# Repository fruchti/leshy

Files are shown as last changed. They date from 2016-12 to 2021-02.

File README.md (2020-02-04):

# leshy

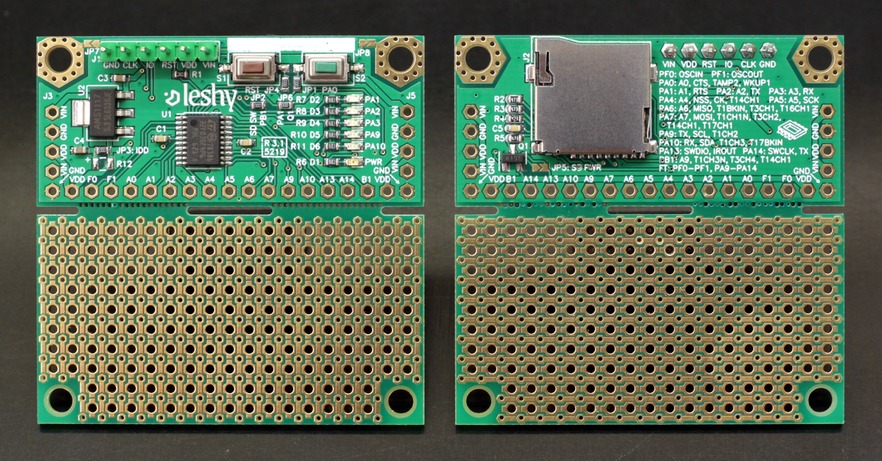
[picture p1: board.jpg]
PCB top and bottom

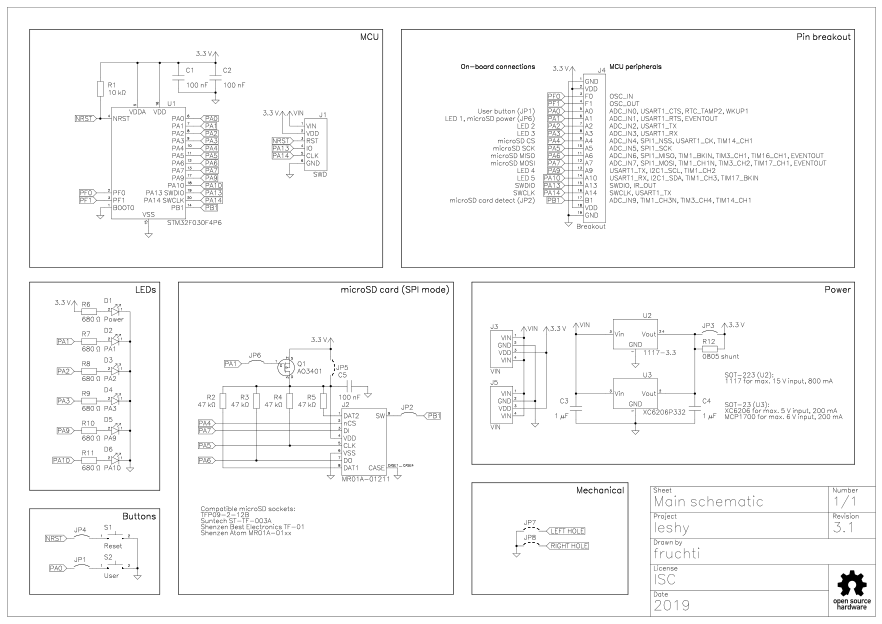
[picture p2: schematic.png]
Schematic


This is a small breakout board for the STM32F030F4P6 microcontroller,
containing:

 - An LDO, alternatively a 1117-3.3 or a MCP1700-3302 (or compatible)
 - 6 LEDs, one as a power LED, the other 5 controllable by the controller
 - Two pushbuttons, one pre-connected to reset
 - A micro-SD slot with a MOSFET for turning its power off
 - A large prototyping area designed to make both SMT and THT prototyping as
   convenient as possible

A blog post about the reasoning behind the project and about its development
process can be found [here](https://25120.org/post/leshy/).

## Demo projects

The subfolder `demo` contains some example code snippets for a quick start. Each
contains the necessary makefile for building and flashing, so no IDE has to be
installed in order to get started. However, the makefile is currently only
tested on linux.

### Flashing and debugging

The makefile currently supports two methods of flashing the controller: Either
[texane's st-link](https://github.com/texane/stlink) or OpenOCD can be used.
OpenOCD also allows debugging, so if the makefile detects a running OpenOCD
instance, it will automatically upload the firmware via OpenOCD. If there's
none running, it will fall back to `st-flash`.

Each project directory includes a OpenOCD script, so you just have to start
OpenOCD like:

```
$ openocd -f flash.cfg
```

As a matter of debugging, only text messages via semihosting are implemented so
far. These are displayed in OpenOCD. See the `debug-print` example for details.
Apart from that, of course `arm-none-eabi-gdb` or a complete IDE can be used.

## Licence

Everyting in this repository, including the demo projects is ISC licenced (see
LICENCE_ISC.md for details), with the following exceptions:

* Third-party libraries used within the demo projects and located in their
  `third_party` subfolders, contain their own licence information.
* Core and device header files, which are also located in the demo projects'
  `third_party` subfolders, are supplied by ARM Limited and STMicroelectronics,
  respecitvely. They also contain their own licence information.
* For compatibility with the Horizon default pool, this project's pool (located
  within `horizon/pool`) uses
  [the same licence as the default pool](https://github.com/horizon-eda/horizon-pool/blob/master/LICENSE.md).
* Horizon automatically copies pool items for caching to the
  `horizon/design/cache` directory. Just being copies, these files also fall
  under the terms of the
  [Horizon Pool Licence](https://github.com/horizon-eda/horizon-pool/blob/master/LICENSE.md).

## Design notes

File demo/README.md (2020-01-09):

# Demo projects

This directory contains some example code snippets for a quick start. Each
contains the necessary makefile for building and flashing, so no IDE has to be
installed in order to get started. However, the makefile is currently only
tested on Linux.

| Folder | Example description |
| --- | --- |
| `blink` | Classic minimal LED blinking example. Implemented with a timer update interrupt |
| `debug-print` | Demonstrates printing messages via semihosting while debugging |
| `FreeRTOS` | Simple FreeRTOS example with tasks blinking an LED, measuring time and transmitting via semihosting |
| `hd44780` | Basic driver for HD44780-compatible character LC displays |
| `sd` | Uses FatFs to log the internal temperature sensor's output to a CSV file on the SD card |
| `soldering_station` | Basic controller for Hakko 907 soldering irons. Includes encoder input, charlieplexed 7-segment driver, control loop, and settings storage in flash memory |
| `ws2812b-hsv` | Sets H, S, V via three potentiometers and light up a WS2812B strip uniformly |
| `ws2812b-spi` | Drives a WS2812B LED strip with the SPI peripheral and DMA |

If you want to use one of the demo projects as a starting point, here is a small
table with the MCU peripherals in use and external components the project
contains driver code for:

| Folder | Microcontroller peripherals | External components | Third-party libraries |
| --- | --- | --- | --- |
| `blink` | `TIM` | | |
| `debug-print` | | | |
| `FreeRTOS` | `SysTick` | | [FreeRTOS](https://freertos.org/) |
| `hd44780` | | HD44780-based display (4-bit mode) | |
| `sd` | `ADC` (internal temperature sensor), `SPI`, `SysTick`, `TIM` | microSD card (SPI mode) | [FatFs](http://elm-chan.org/fsw/ff/00index_e.html) |
| `soldering_station` | `ADC`, `FLASH` (non-volatile storage), `TIM` | 7-segment display (charlieplexed), rotary encoder | |
| `ws2812b-hsv` | `ADC`, `DMA`, `TIM` | WS2812B LED strip (uniform colour) | |
| `ws2812b-spi` | `DMA`, `SPI`, `TIM` | WS2812B LED strip | |

## Flashing

The makefile supports flashing the controller via
[texane's st-link](https://github.com/texane/stlink). Invoke

```
$ make program
```

to build a binary and flash it at `0x8000000`.

# Debugging

Each project directory includes a OpenOCD script, so you can start OpenOCD like:

```
$ openocd -f flash.cfg
```

As a matter of debugging, only text messages via semihosting are implemented so
far. These are displayed in OpenOCD. See the `debug-print` example for details.
Apart from that, of course `arm-none-eabi-gdb` or a complete IDE can be used.

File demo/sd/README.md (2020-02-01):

# SD card example

This example reads out the microcontroller's internal temperature sensor every
n milliseconds and saves the values to `log.csv` on the SD card. Logging is
stopped and started again by clicking the switch attached to PA0.

LED 3 (PA3) indicates ongoing initialisation, while LED 2 (PA2) is lit up as
long as logging is taking place. LED 5 (PA 10) flashes for every saved data
point. LED 1 (PA1) lights up when the SD card is turned off, since it is
connected to the same pin as the SD power MOSFET's gate.

The button should be pressed before removing the SD card, because the write
cache would not be flushed otherwise.

`plot.py` is a minimal Python script to plot a CSV file generated by the code
example.
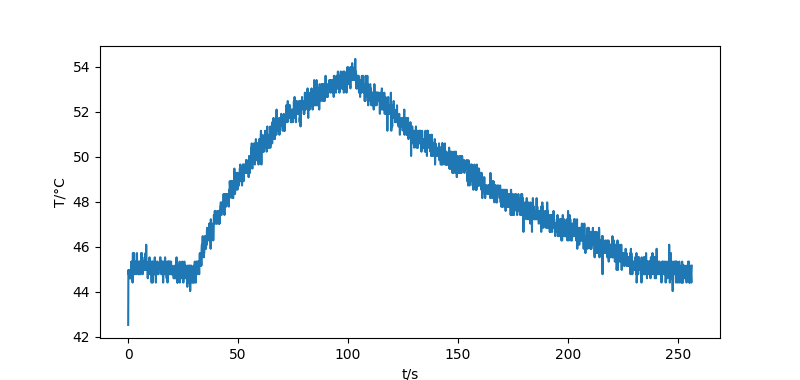
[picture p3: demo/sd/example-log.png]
Example temperature log plot


## Some notes on the code
The code just is a quick port of ELM ChaN's FatFs and could be optimised in
terms of speed and size. The former can be achieved by disabling unneeded
features in `ffconf.h` such as long file names. For the latter an
implementation using the DMA for larger blocks instead of the currently used
blocking SPI transfer.

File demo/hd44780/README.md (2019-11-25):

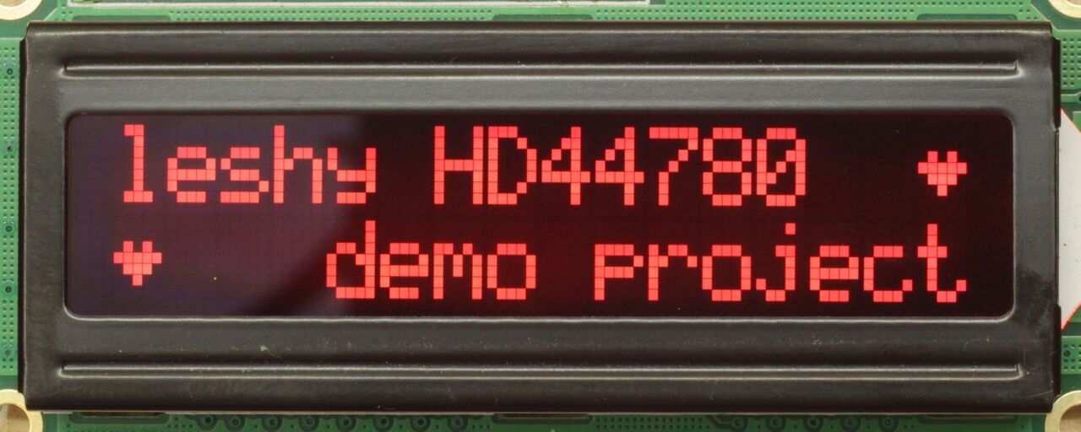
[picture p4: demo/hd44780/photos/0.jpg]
HD44780 example
# 

This is a very basic driver implementation for HD44780-compatible LC displays in
4 bit mode. Delays are blocking for simplicity. Custom characters are supported
(as shown in the photo above). The used pins can be moved around freely in
`pinning.h`, but are constrained to port A. If they have to be moved to another
port, `LCD_Init()` and `LCD_Nibble()` have to be adapted accordingly.

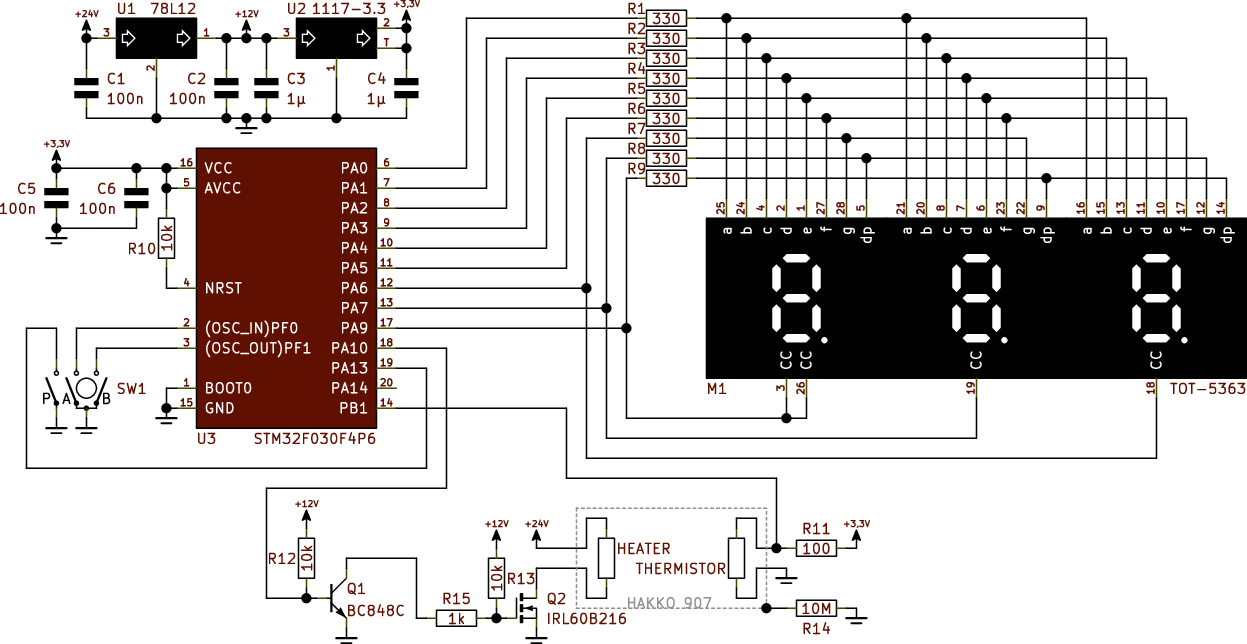
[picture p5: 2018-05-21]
demo/soldering_station/schematic/schematic.png

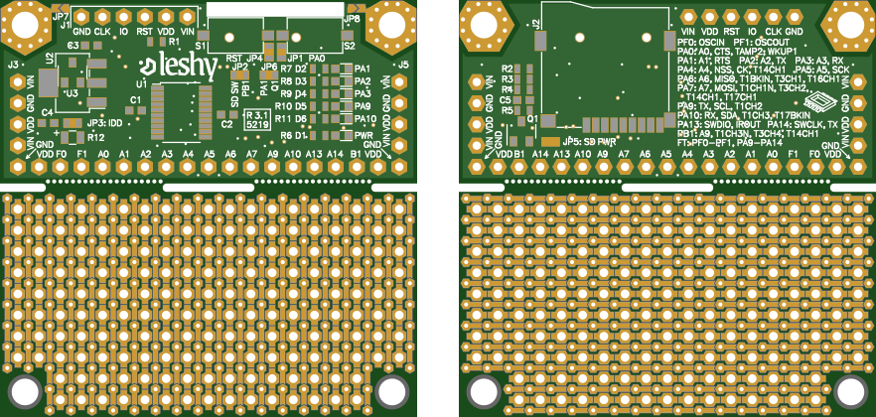
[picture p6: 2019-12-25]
layout.png

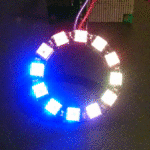
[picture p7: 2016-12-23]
demo/ws2812b-spi/demo.gif

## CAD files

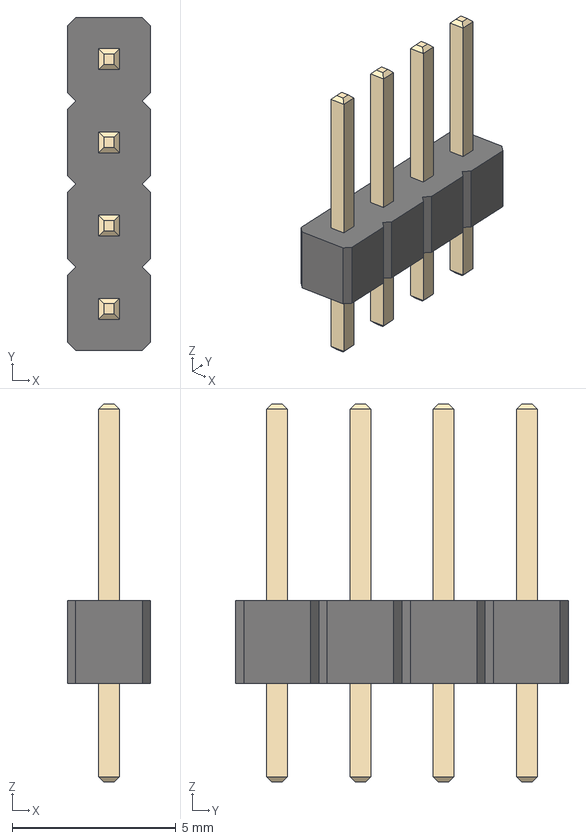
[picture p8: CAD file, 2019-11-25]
horizon/design/cache/3d_models/pool_6d752bc3-29b3-45df-8cf2-1e3aacefbcc6/3d_models/connector/header/2.54mm/PinHeader_1x04_P2.54mm_Vertical.step
2.54 x 10.2 x 11.5 mm

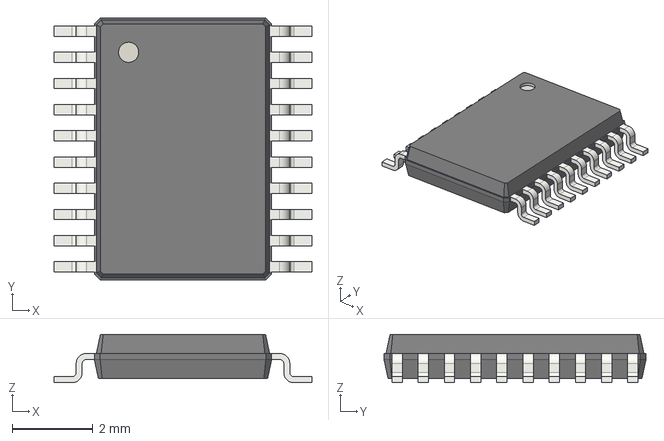
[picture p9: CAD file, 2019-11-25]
horizon/design/cache/3d_models/pool_6d752bc3-29b3-45df-8cf2-1e3aacefbcc6/3d_models/ic/so/TSSOP-20_4.4x6.5mm_P0.65mm.step
6.40 x 6.50 x 1.20 mm

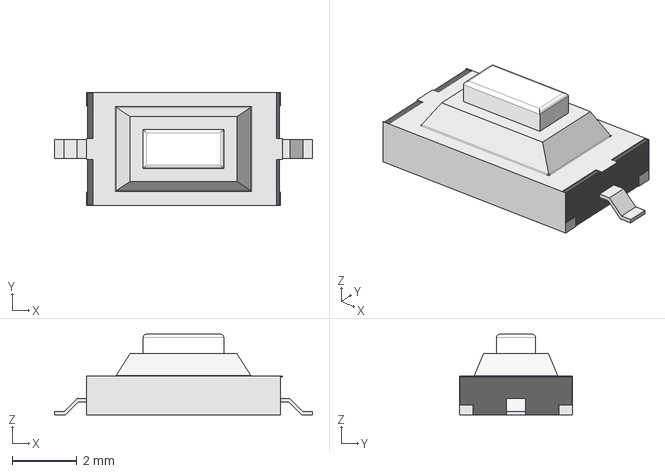
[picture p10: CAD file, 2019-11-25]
horizon/design/cache/3d_models/pool_6d752bc3-29b3-45df-8cf2-1e3aacefbcc6/3d_models/mechanical/switch/PTS636SM25SMTR.step
8.00 x 3.50 x 2.50 mm

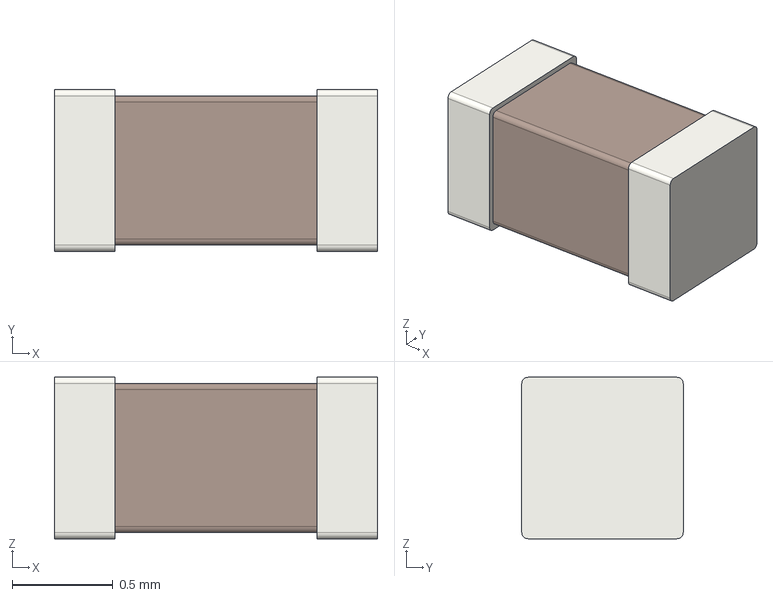
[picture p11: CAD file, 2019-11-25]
horizon/design/cache/3d_models/pool_6d752bc3-29b3-45df-8cf2-1e3aacefbcc6/3d_models/passive/capacitor/C_0603_1608Metric.step
1.60 x 0.8 x 0.8 mm

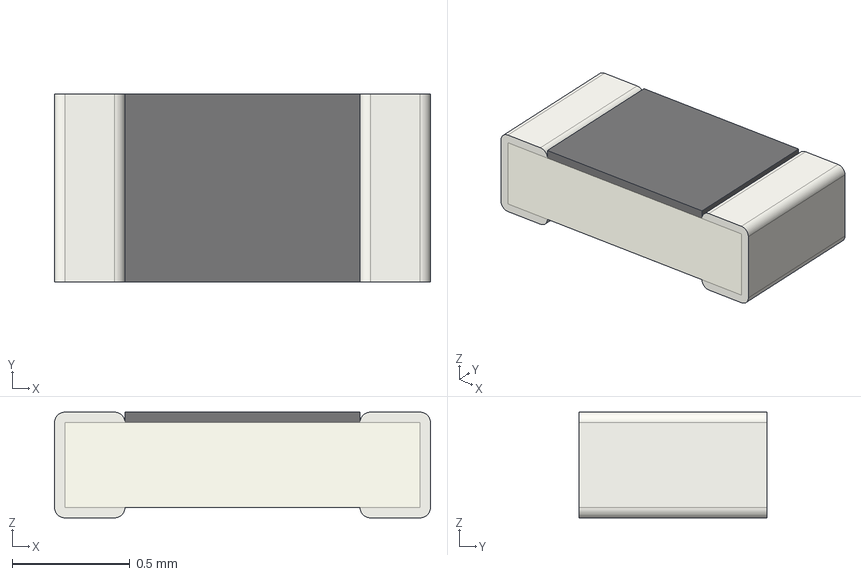
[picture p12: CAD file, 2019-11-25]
horizon/design/cache/3d_models/pool_6d752bc3-29b3-45df-8cf2-1e3aacefbcc6/3d_models/passive/resistor/R_0603_1608Metric.step
1.60 x 0.8 x 0.45 mm

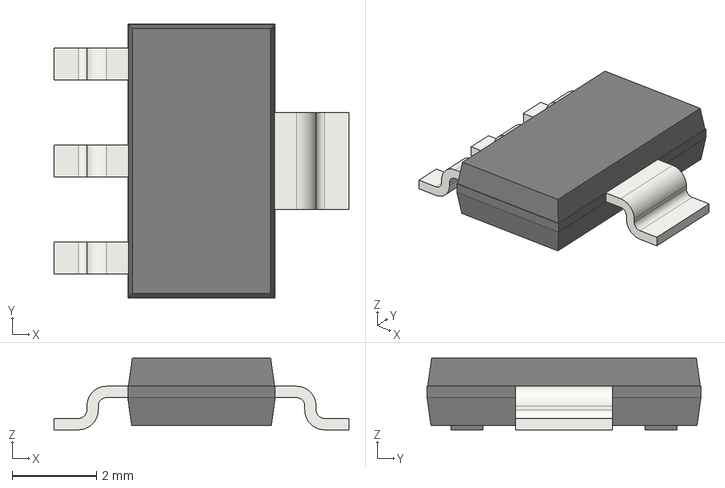
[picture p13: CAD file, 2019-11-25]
horizon/design/cache/3d_models/pool_6d752bc3-29b3-45df-8cf2-1e3aacefbcc6/3d_models/sot/SOT-223.step
7.00 x 6.50 x 1.70 mm

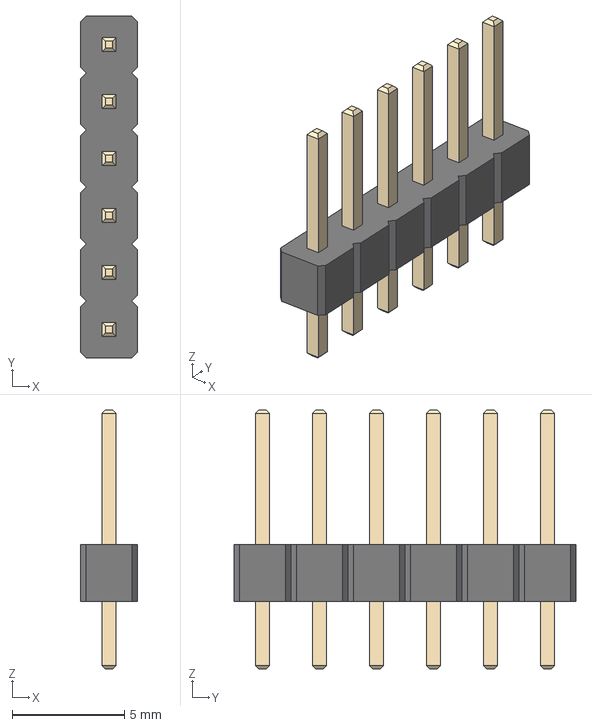
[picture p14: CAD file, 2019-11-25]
horizon/pool/3d_models/connector/header/2.54mm/PinHeader_1x06_P2.54mm_Vertical.step
2.54 x 15.2 x 11.5 mm

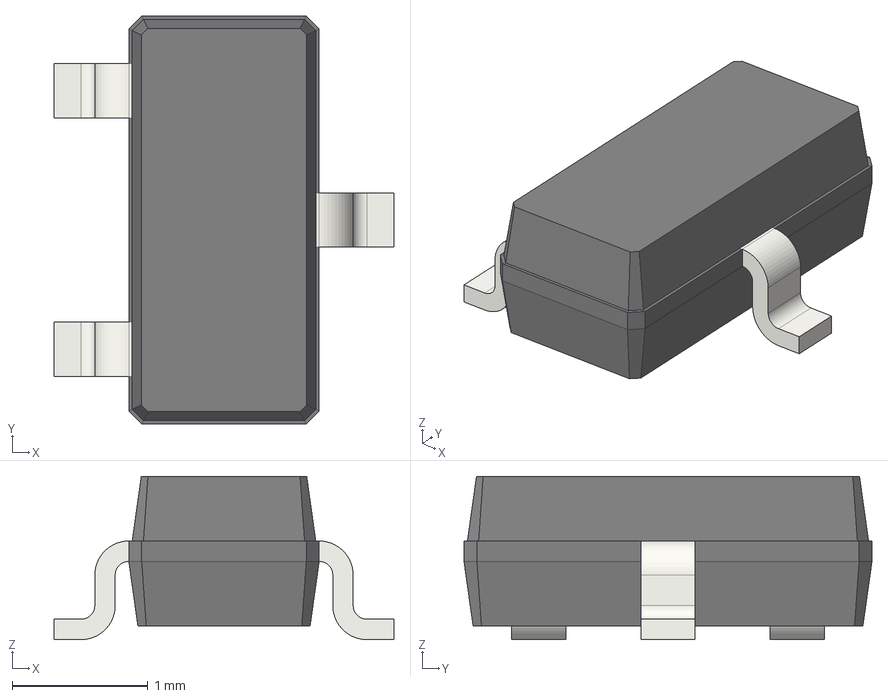
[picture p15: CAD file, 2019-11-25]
horizon/design/cache/3d_models/pool_6d752bc3-29b3-45df-8cf2-1e3aacefbcc6/3d_models/ic/so/SOT-23.step
2.50 x 3.00 x 1.20 mm

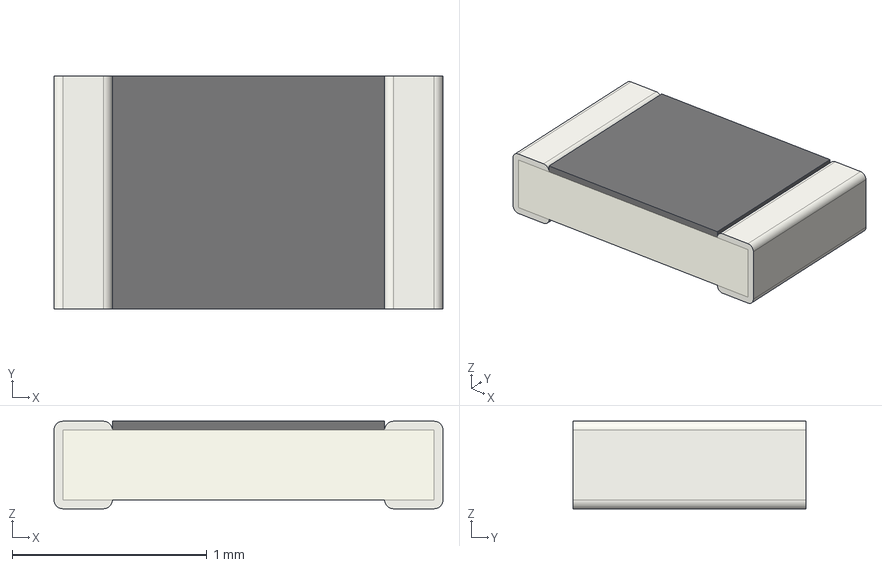
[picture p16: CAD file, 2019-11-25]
horizon/design/cache/3d_models/pool_6d752bc3-29b3-45df-8cf2-1e3aacefbcc6/3d_models/passive/resistor/R_0805_2012Metric.step
2.00 x 1.20 x 0.45 mm

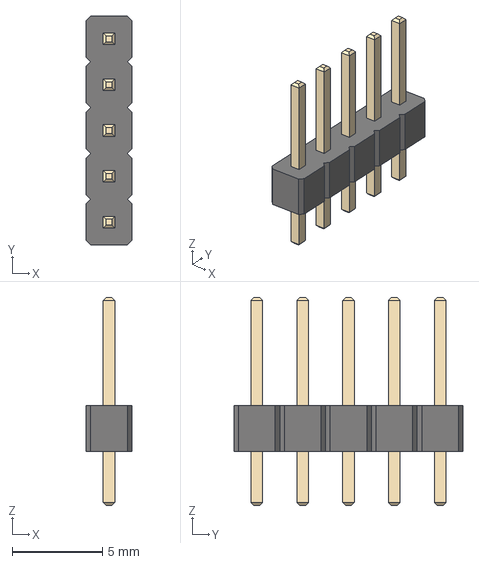
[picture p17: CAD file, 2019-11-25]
horizon/pool/3d_models/connector/header/2.54mm/PinHeader_1x05_P2.54mm_Vertical.step
2.54 x 12.7 x 11.5 mm

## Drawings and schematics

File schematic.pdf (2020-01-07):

## MCU

## Pin breakout

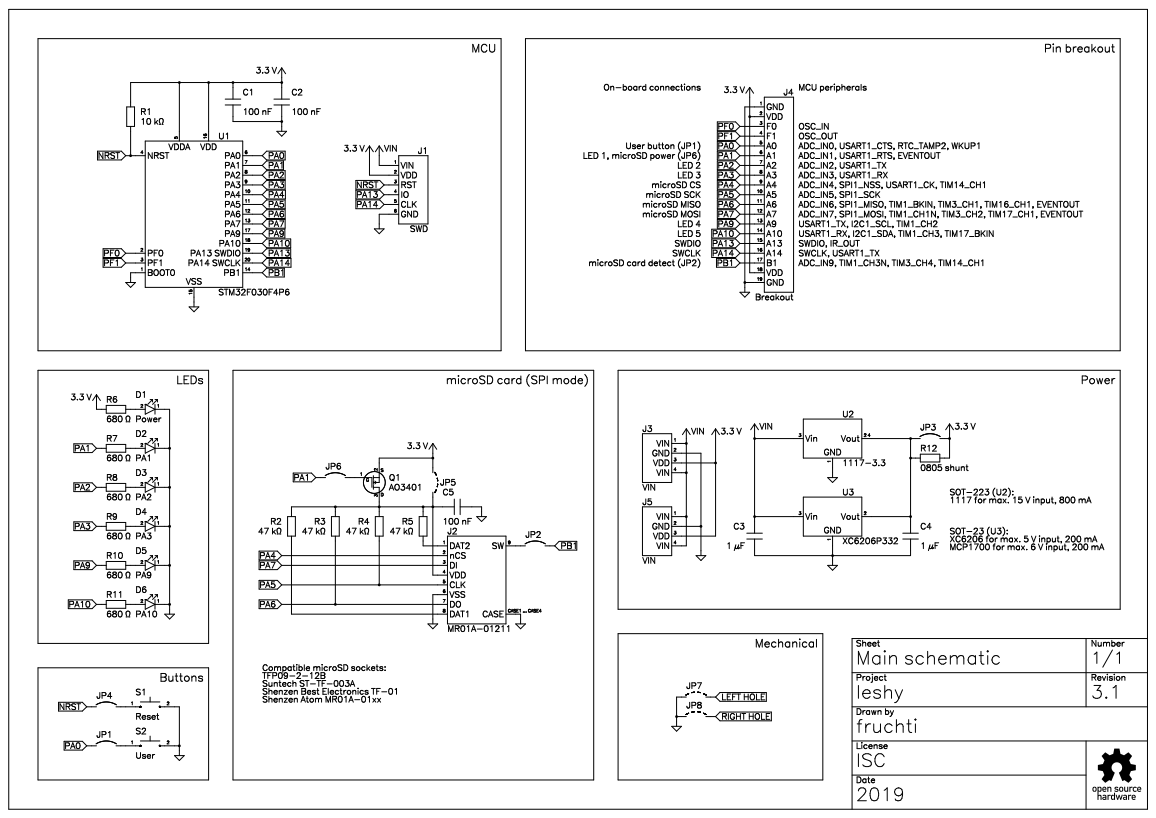
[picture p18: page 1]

microSD card (SPI mode)

SOT-223 (U2):
1117 for max. 15 V input, 800 mA

SOT-23 (U3):
XC6206 for max. 5 V input, 200 mA
MCP1700 for max. 6 V input, 200 mA

Sheet Main schematic | Number

Compatible microSD sockets:
TFP09-2-12B
Suntech ST-TF-003A
Shenzen Best Electronics TF-01
Shenzen Atom MR01A-01xx

Project | Revision

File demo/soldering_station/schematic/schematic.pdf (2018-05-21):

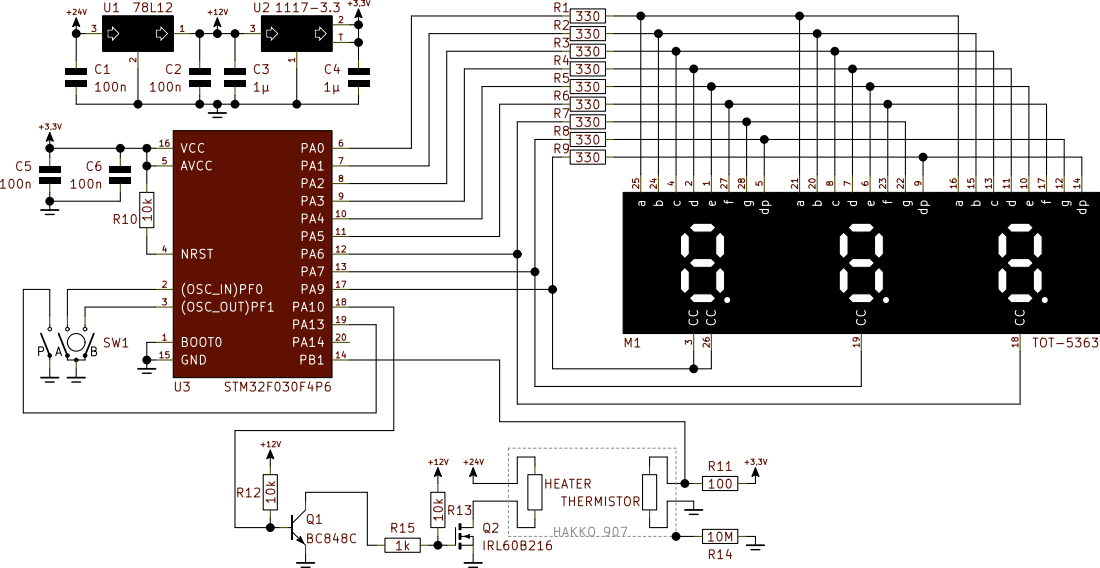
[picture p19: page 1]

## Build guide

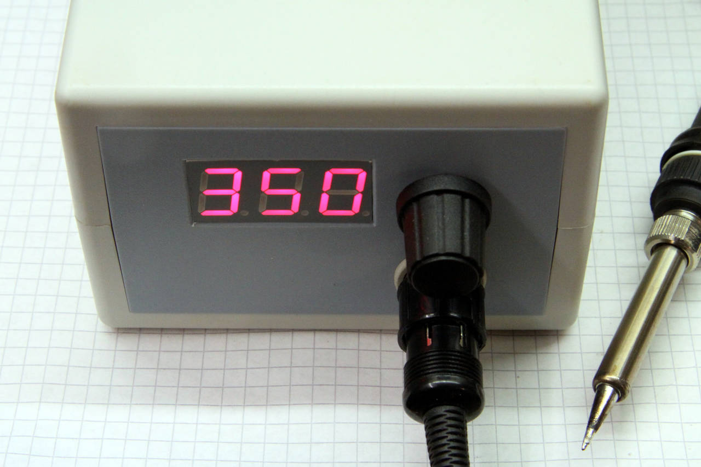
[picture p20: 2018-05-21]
demo/soldering_station/photos/0.jpg

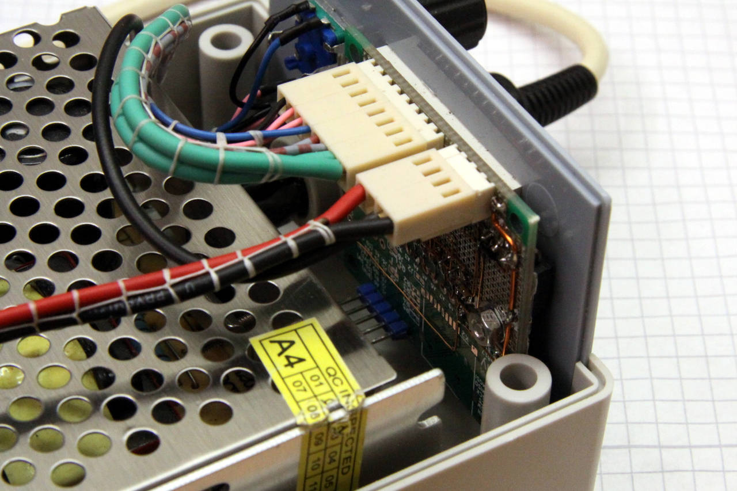
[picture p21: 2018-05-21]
demo/soldering_station/photos/1.jpg

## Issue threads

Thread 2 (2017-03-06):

Makefile does not generate dependencies for third-party libraries

fruchti, 2017-03-06:
For libraries not in `src` (like FatFs), the makefile does not generate dependency files. Therefore, C files are not correctly recompiled after changing a corresponding header. This is a minor issue, as third-party libraries are not changed that much usually.

In my eyes, the correct way to deal with this would be to treat the libraries just like the code in `src`, resp. the other way round. Currently, there is a unnecessary differentiation between those source directories although they could be treated alike.

fruchti, 2017-04-02:
Just like proposed, the makefile treats every C source directory the same now.

Closed 2017-04-02.

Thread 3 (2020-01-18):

SD card example doesn't drive VDD MOSFET

fruchti, 2020-01-18:
The FatFs example is still from revision 1 and does not account for the option for a power enable MOSFET (possible since board revision 2.0).

Closed 2020-02-01.

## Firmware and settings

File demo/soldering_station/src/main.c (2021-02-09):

#include "main.h"

volatile int SetTemperatureDisplayCounter = 2 * CONFIG_SET_DISPLAY_TIME
    + 7 * CONFIG_SEGMENT_TEST_TIME + CONFIG_BUILD_DISPLAY_TIME;
volatile int DisplayUpdateCounter = 0;
volatile bool NVSSavePending = false;

int main(void)
{
    RCC->AHBENR |= RCC_AHBENR_GPIOBEN;
    RCC->APB2ENR |= RCC_APB2ENR_TIM16EN;

    TIM16->PSC = 47;
    TIM16->ARR = 1000;
    TIM16->DIER = TIM_DIER_UIE;
    NVIC_EnableIRQ(TIM16_IRQn);
    TIM16->CR1 = TIM_CR1_ARPE | TIM_CR1_CEN;

    Display_Init();

    NVS_Load();
    PID_SetTemperature = NVS_Data->set_temperature;

    PID_Init();
    Encoder_Init();
    
    while(1)
    {
        __WFI();
        int delta = Encoder_Read();
        if(delta != 0)
        {
            PID_SetTemperature += delta;
            if(PID_SetTemperature > CONFIG_MAX_TEMP)
            {
                PID_SetTemperature = CONFIG_MAX_TEMP;
            }
            else if(PID_SetTemperature < CONFIG_MIN_TEMP)
            {
                PID_SetTemperature = CONFIG_MIN_TEMP;
            }
            SetTemperatureDisplayCounter = CONFIG_SET_DISPLAY_TIME;
        }

        if(SetTemperatureDisplayCounter > 0)
        {
            Display_Number(PID_SetTemperature);
            Display_Blinking = true;
        }
        else
        {
            if(DisplayUpdateCounter == 0)
            {
                DisplayUpdateCounter = CONFIG_UPDATE_INTERVAL;
                if(PID_CurrentTemperature != -1)
                {
                    Display_Number(PID_CurrentTemperature);
                }
                else
                {
                    Display_ShowSegments(DISPLAY_SEG_G, DISPLAY_SEG_G,
                        DISPLAY_SEG_G);
                }
                Display_Blinking = false;
            }
        }

        if(NVSSavePending)
        {
            NVSSavePending = false;
            NVS_Data->set_temperature = PID_SetTemperature;
            NVS_Save(true);
        }
    }

    return 0;
}

void TIM16_IRQHandler(void)
{
    Encoder_Poll();

    if(SetTemperatureDisplayCounter > 0)
    {
        SetTemperatureDisplayCounter--;
        if(SetTemperatureDisplayCounter == 0)
        {
            NVSSavePending = true;
        }
    }
    if(DisplayUpdateCounter > 0)
    {
        DisplayUpdateCounter--;
    }

    TIM16->SR &= ~TIM_SR_UIF;
}

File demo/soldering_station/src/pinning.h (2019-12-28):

#pragma once

// Port A
#define PIN_DISP_1_SEG_A        0   // PA0  - Decimal 1 segment a
#define PIN_DISP_1_SEG_B        1   // PA1  - Decimal 1 segment b
#define PIN_DISP_1_SEG_C        2   // PA2  - Decimal 1 segment c
#define PIN_DISP_1_SEG_D        3   // PA3  - Decimal 1 segment d
#define PIN_DISP_1_SEG_E        4   // PA4  - Decimal 1 segment e
#define PIN_DISP_1_SEG_F        5   // PA5  - Decimal 1 segment f
#define PIN_DISP_1_SEG_G        6   // PA6  - Decimal 1 segment g
#define PIN_DISP_1_DP           7   // PA7  - Decimal 1 decimal point
#define PIN_DISP_1_COMMON       9   // PA9  - Decimal 1 common

#define PIN_DISP_2_SEG_A        0   // PA0  - Decimal 2 segment a
#define PIN_DISP_2_SEG_B        1   // PA1  - Decimal 2 segment b
#define PIN_DISP_2_SEG_C        2   // PA2  - Decimal 2 segment c
#define PIN_DISP_2_SEG_D        3   // PA3  - Decimal 2 segment d
#define PIN_DISP_2_SEG_E        4   // PA4  - Decimal 2 segment e
#define PIN_DISP_2_SEG_F        5   // PA5  - Decimal 2 segment f
#define PIN_DISP_2_SEG_G        6   // PA6  - Decimal 2 segment g
#define PIN_DISP_2_DP           9   // PA9  - Decimal 2 decimal point
#define PIN_DISP_2_COMMON       7   // PA7  - Decimal 2 common

#define PIN_DISP_3_SEG_A        0   // PA0  - Decimal 3 segment a
#define PIN_DISP_3_SEG_B        1   // PA1  - Decimal 3 segment b
#define PIN_DISP_3_SEG_C        2   // PA2  - Decimal 3 segment c
#define PIN_DISP_3_SEG_D        3   // PA3  - Decimal 3 segment d
#define PIN_DISP_3_SEG_E        4   // PA4  - Decimal 3 segment e
#define PIN_DISP_3_SEG_F        5   // PA5  - Decimal 3 segment f
#define PIN_DISP_3_SEG_G        7   // PA7  - Decimal 3 segment g
#define PIN_DISP_3_DP           9   // PA9  - Decimal 3 decimal point
#define PIN_DISP_3_COMMON       6   // PA6  - Decimal 3 common

#define PIN_PWM                 10  // PA10 - TIM1_CH3

#define PIN_ENC_P               13  // PA13 - Encoder pushbutton
#define PIN_SENSOR              14  // PA14 - Motion sensor

// Port B
#define PIN_PTC                 1   // PB1  - ADC1_IN9

// Port F
#define PIN_ENC_A               0   // PF0  - Encoder phase A
#define PIN_ENC_B               1   // PF1  - Encoder phase B

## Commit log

2016-12-23 Add WS2812B example
    [flash.cfg]
2017-02-21 Add SD card example
    [flash.cfg]
2017-02-23 Ditch sd.c/sd.h, optimise a bit
    [example-log.csv]
2017-03-06 Fix interrupt flag typo, reverse blinking pattern
    [main.c]
2017-04-02 Add PCB render
    [leshy-B.Cu.gbl, leshy-B.Mask.gbs, leshy-B.SilkS.gbo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]
2017-04-16 Switch to newlib nano
2017-04-16 Fix HardFault occurring when not attached to debugger
    Because DHCSR cannot be read from the CPU on Cortex M0 devices, a
    workaround had to be used. The code is based on
    https://www.lpcware.com/content/forum/how-to-detect-if-lpclink-is-attached-
2017-04-16 Add FreeRTOS example
    [flash.cfg]
2017-11-27 Add new board revision
    Main differences are:
    - The SD card now has a MOSFET, so it can be completely shut off
    - More (hopefully useful) silkscreen text
    - Logo on board
    [leshy-B.Cu.gbl, leshy-B.Mask.gbs, leshy-B.SilkS.gbo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]
2017-11-27 Add new revision's PDF schematic
2017-12-26 Move submodules, common files to demo/common/
    [flash.cfg]
2018-05-21 Add soldering station example
    [soldering_station.kicad_pcb, soldering_station.sch]
2018-12-19 Add nonvolatile storage for temperature setting
2019-05-18 Add schematic to README
2019-05-18 Add link to PDF schematic
2019-11-15 Add WS2812B HSV controller example
    [flash.cfg]
2019-11-16 Make all examples self-contained
    STM32CUBEMX is no longer a dependency and all examples build
    independently from the previously existing `common` folder.
    [flash.cfg]
2019-11-25 Add HD44780 example
    [flash.cfg]
2019-11-25 Remove KiCad files
    [leshy-B.Cu.gbl, leshy-B.Mask.gbs, leshy-B.SilkS.gbo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]
2019-11-25 Add Horizon pool and design for R 3.0
    [C_0603_1608Metric.step, PTS636SM25SMTR.step, PinHeader_1x04_P2.54mm_Vertical.step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]
2019-11-25 Add gerber files for R 3.0
    [leshy.gbl, leshy.gbo, leshy.gbp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]
2019-12-25 Rev. 3.1: Move vias for silkscreen legibility
    [leshy.gbl, leshy.gbs, leshy.gtl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]
2019-12-25 Update README, add schematic PDF
2019-12-28 Replace include guards with pragma once
    [pid.h]
2020-01-07 Schematic: Fix hardware revision
2020-01-17 Replace board render with photograph
2020-02-01 SD example: Drive MOSFET (fixes #3)
    [main.c, pinning.h]
2020-02-01 SD example: Turn off again if initialisation fails
    [main.c]
2021-02-09 Soldering station demo: Improve NVS module
    * Write/erase failures no longer lock up the system
    * Erasing can now be disabled when writing to NVS
    [main.c]

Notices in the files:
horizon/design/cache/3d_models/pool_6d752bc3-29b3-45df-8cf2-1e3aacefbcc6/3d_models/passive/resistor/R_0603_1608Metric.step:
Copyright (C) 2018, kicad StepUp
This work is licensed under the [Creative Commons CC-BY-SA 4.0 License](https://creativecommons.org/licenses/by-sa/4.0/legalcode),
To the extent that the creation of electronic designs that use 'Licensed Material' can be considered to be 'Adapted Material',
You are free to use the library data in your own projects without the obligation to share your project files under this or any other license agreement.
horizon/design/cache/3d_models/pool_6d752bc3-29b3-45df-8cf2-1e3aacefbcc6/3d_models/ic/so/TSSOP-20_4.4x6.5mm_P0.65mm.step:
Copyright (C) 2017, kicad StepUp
